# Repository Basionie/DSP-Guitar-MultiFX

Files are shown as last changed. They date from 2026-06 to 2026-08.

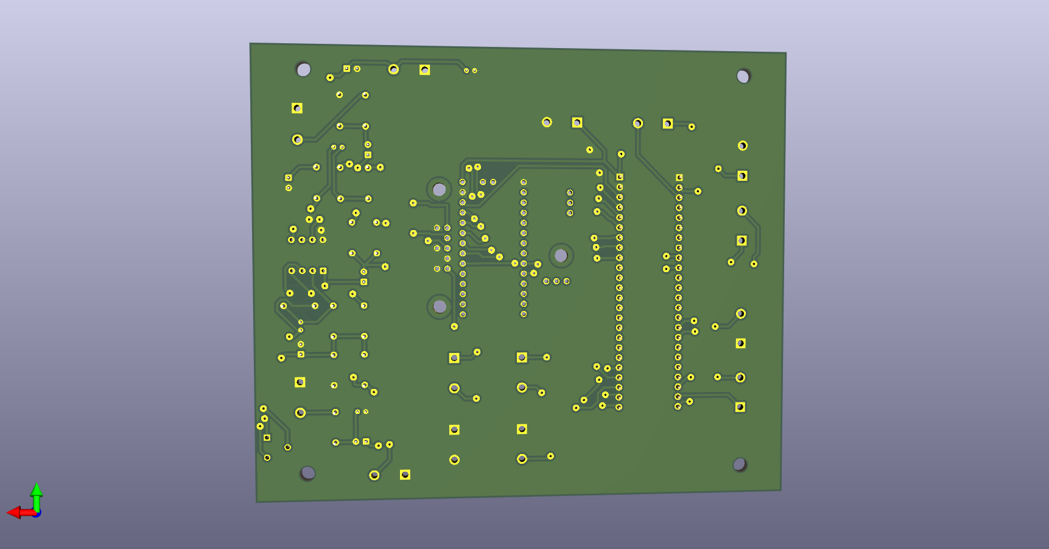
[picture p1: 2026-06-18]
Images/pcb_bottom_3d.png

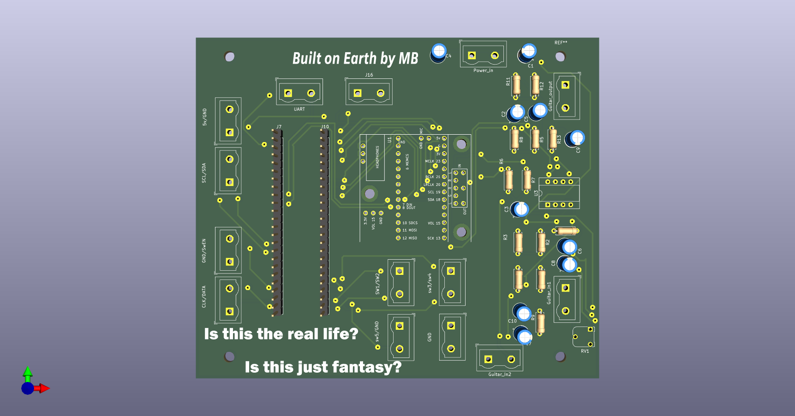
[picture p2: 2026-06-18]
Images/pcb_top_3d.png

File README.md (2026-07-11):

# DSP-Guitar-MultiFX

A modular, high-performance guitar multi-effects processor built on the Teensy 4.1. This project features a professional-grade audio graph, real-time parameter control, and a scalable architecture for adding new audio effects.

🛠️ Features
Modular Architecture: Isolated namespaces for DSP, audio routing, and UI logic.

Audio Effects: Currently supports Chorus, Delay, and Reverb.

Hardware Interface: Integrated support for SGTL5000 audio shield, rotary encoder for navigation, and display integration.

Scalable Design: Easily add new effects by implementing the IEffect interface.

🚀 Getting Started
Clone the repository: git clone [https://github.com/Basionie/DSP-Guitar-MultiFX.git](https://github.com/Basionie/DSP-Guitar-MultiFX.git)

Setup: Open the firmware/ folder in VS Code with the PlatformIO extension.

Build: Use the PlatformIO "Build" button to compile the firmware.

Upload: Connect your Teensy 4.1 via USB and click "Upload".

⚙️ How to Add New Effects
To add a new effect (e.g., Distortion):

Create effects/distortion.h and distortion.cpp.

Implement the IEffect interface.

Register the new effect in the EffectManager to enable UI control.

📜 Dependencies
U8g2 (Display driver)

CriticalTaskScheduler 
(Task scheduling)

7448d674-3cfc-4cf9-ab88-5cb7c3a28c2d

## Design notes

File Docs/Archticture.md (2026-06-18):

# DSP Guitar Effects Pedal Architecture (Teensy 4.1)

## System Overview

The system is a real-time digital audio processing pedal built on the Teensy 4.1 microcontroller.

A guitar input signal is captured, processed through a modular DSP effects chain, and output with minimal latency suitable for live performance.

---

## Signal Flow

Guitar Input  
→ Analog Front-End (signal conditioning)  
→ Audio Codec (ADC via SGTL5000)  
→ Teensy 4.1 DSP Processing Core  
→ Effects Processing Chain  
→ Audio Codec (DAC)  
→ Output to amplifier / speaker

---

## DSP Processing Pipeline

Audio is processed in real time using a block-based streaming architecture:

1. Audio buffer acquisition (input block)
2. Pre-processing (gain control / normalization)
3. Effects chain processing:
   - Distortion (non-linear waveshaping)
   - Delay (buffer-based echo)
   - Reverb (Algorithmic Reverb)
4. Mixing and output gain control
5. Output buffer transmission

---

## Hardware Architecture

- Teensy 4.1 (ARM Cortex-M7 @ 600 MHz)
- Audio Shield (SGTL5000 codec)
- Guitar input jack with analog conditioning circuit
- Audio output to amplifier or speaker system

---

## Software Architecture

The firmware is modular and built around the Teensy Audio Library.

Main components:

- `audio_input.cpp` → Handles audio input stream
- `audio_engine.cpp` → Manages DSP pipeline and routing
- `effects/` → Individual effect modules (distortion, delay, reverb)
- `config.h` → Global parameters (gain, mix, effect levels)

The system uses interrupt-driven, real-time audio processing with fixed-size audio blocks.

---

## Real-Time Constraints

- Target latency: < 10 ms
- Block-based processing using Teensy Audio Library
- Optimized for ARM Cortex-M7 DSP instructions
- No dynamic memory allocation in the audio processing path
- Deterministic execution per audio block

---

## Expandability

The architecture is designed to support future enhancements:

- Footswitch / pedal control input
- Preset saving and loading system
- External UI (OLED display)

---

## Summary

This architecture provides a scalable and real-time DSP framework for guitar audio processing on embedded hardware, balancing performance, modularity, and low latency.

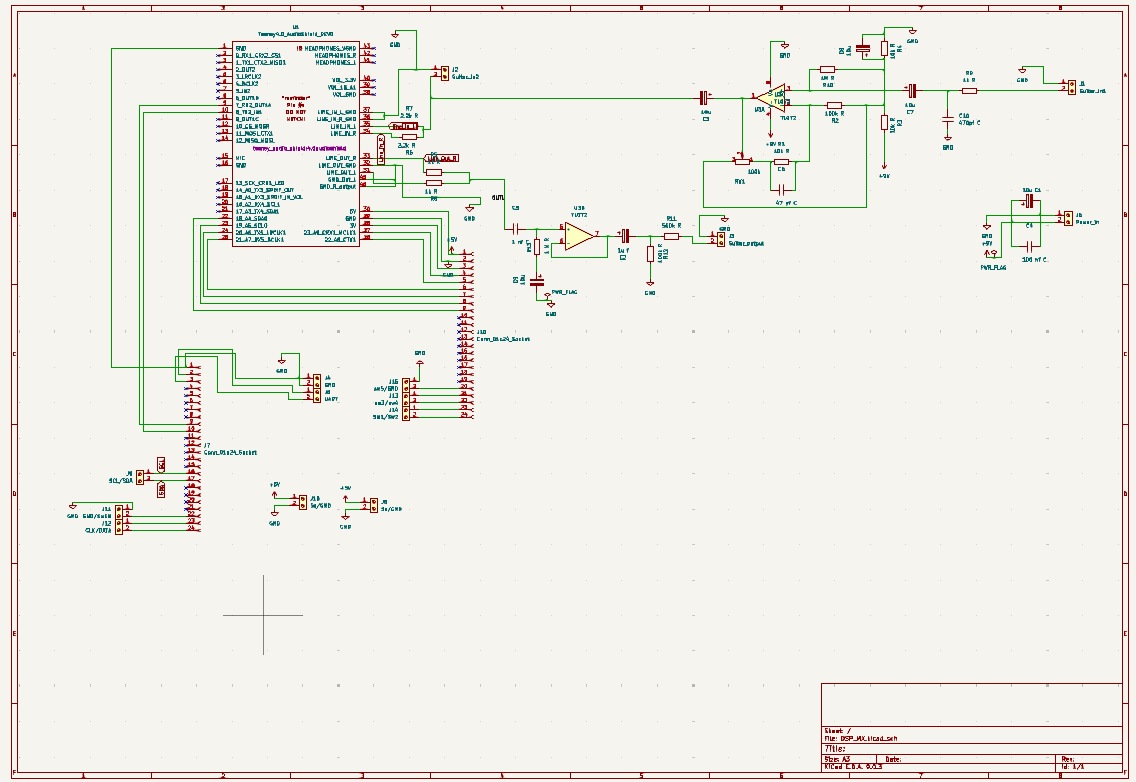
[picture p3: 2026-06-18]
Images/schematic.png

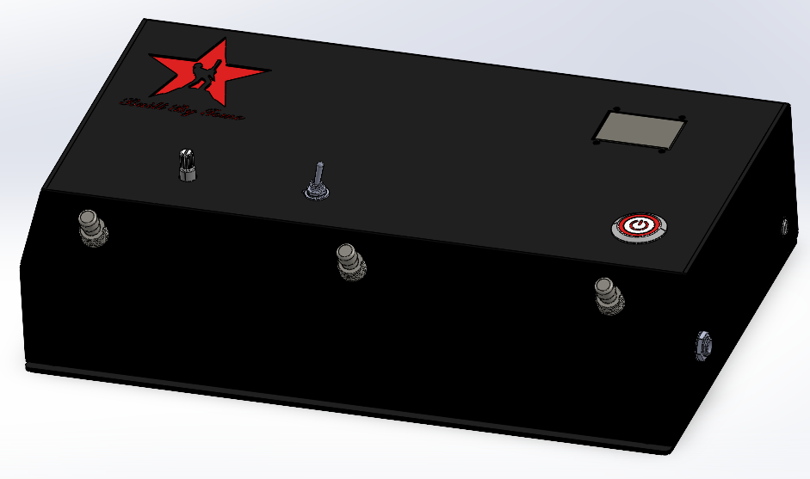
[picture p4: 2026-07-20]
Images/DSP_Final_Desing.png

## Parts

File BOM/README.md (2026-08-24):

# Bill of Materials (BOM)

> **Note:** The components listed in this BOM were primarily sourced from local suppliers in Egypt in prototyping/non-production quantities. Prices are provided for reference only.

Please refer to [`Project_BOM.xlsx`](./Project_BOM.xlsx) for the full itemized components list and cost analysis.

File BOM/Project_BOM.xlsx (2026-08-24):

HARDWARE PROJECT BILL OF MATERIALS (BOM)
The components listed in this BOM were primarily purchased from suppliers in Egypt and in non-production quantities. Prices are provided for reference only and may vary depending on the supplier, country, exchange rates, availability, and purchase quantity. Bulk or mass-production purchases may have significantly different pricing.
Item | Component | Value / Specification | Manufacturer | Part Number | Quantity | Unit Price (EGP) | Total (EGP) | Unit Price (USD) | Total (USD) | Source | Link
1 | Microcontroller | Teensy 4.1 Board | PJRC | DEV-16771 | 1 | 1575.00 | 1575.00 | $31.50 | $31.50 | SparkFun | https://www.sparkfun.com/teensy-4-1.html
2 | Audio Codec | Teensy 4 Audio Shield (Rev D) | PJRC | DEV-15845 | 1 | 490.00 | 490.00 | $9.80 | $9.80 | SparkFun | https://www.sparkfun.com/teensy-4-audio-shield-rev-d.html
3 | Op-Amp | Low Noise JFET Dual Operational Amplifier | Generic / ST | TL072CN | 2 | 17.00 | 34.00 | $0.34 | $0.68 | RAM Electronics | https://www.ram-e-shop.com/ar/shop/tl072-tl072cn-5722
4 | Capacitor | 10 µF | Generic | C.10U450V | 1 | 3.50 | 3.50 | $0.07 | $0.07 | RAM Electronics | https://www.ram-e-shop.com/ar/shop/c-10u450v-capacitor-mkthf-kymyyy-10uf-mykrw-frd-450v-fwlt-6105
5 | Capacitor | 1 µF | Generic | C.1U50V | 1 | 0.65 | 0.65 | $0.01 | $0.01 | RAM Electronics | https://www.ram-e-shop.com/ar/shop/c-1u50v-capacitor-mkthf-kymyyy-1uf-mykrw-frd-50v-fwlt-6075
6 | Capacitor | 100 nF Ceramic | Generic | C.PF.104 | 2 | 0.75 | 1.50 | $0.01 | $0.03 | RAM Electronics | https://www.ram-e-shop.com/ar/shop/c-pf-104-capacitor-mkthf-pf104-syrmyk-100-nnw-frd-25-fwlt-100nf-25v-6240
7 | Capacitor | 1 nF Ceramic | Generic | C.PF.102 | 1 | 0.50 | 0.50 | $0.01 | $0.01 | RAM Electronics | https://www.ram-e-shop.com/ar/shop/c-pf-102-capacitor-mkthf-pf102-syrmyk-1-nnw-frd-25-fwlt-1nf-25v-6239
8 | Capacitor | 4.7 µF | Generic | C.4.7U50V | 2 | 0.75 | 1.50 | $0.01 | $0.03 | Lampatronics | https://www.ram-e-shop.com/ar/shop/c-4-7u50v-capacitor-mkthf-kymyyy-4-7uf-mykrw-frd-50v-fwlt-6066
9 | Capacitor | 100 µF | Generic | C.100U50V | 1 | 1.50 | 1.50 | $0.03 | $0.03 | Lampatronics | https://www.ram-e-shop.com/ar/shop/c-100u50v-capacitor-mkthf-kymyyy-100uf-mykrw-frd-50v-fwlt-6073
10 | Resistor | 10 kΩ 1/4W Carbon Film | Generic | R.10k.1/4W | 2 | 0.25 | 0.50 | $0.01 | $0.01 | RAM Electronics | https://www.ram-e-shop.com/ar/shop/carbon-resistance-1-4w-price-per-4-resistors-9506#attr=314
11 | Resistor | 100 kΩ 1/4W Carbon Film | Generic | R.100K.1/4W | 2 | 0.25 | 0.50 | $0.01 | $0.01 | RAM Electronics | https://www.ram-e-shop.com/ar/shop/carbon-resistance-1-4w-price-per-4-resistors-9506#attr=317
12 | Resistor | 1 kΩ 1/4W Carbon Film | Generic | R.1K.1/4W | 2 | 0.25 | 0.50 | $0.01 | $0.01 | RAM Electronics | https://www.ram-e-shop.com/ar/shop/carbon-resistance-1-4w-price-per-4-resistors-9506#attr=309
13 | Resistor | 2.2k Ω 1/4W Carbon Film | Generic | R.2.2K.1/4W | 2 | 0.25 | 0.50 | $0.01 | $0.01 | RAM Electronics | https://www.ram-e-shop.com/ar/shop/carbon-resistance-1-4w-price-per-4-resistors-9506#attr=310
14 | Resistor | 1M Ω 1/4W Carbon Film | Generic | R.1M.1/4W | 2 | 0.25 | 0.50 | $0.01 | $0.01 | RAM Electronics | https://www.ram-e-shop.com/ar/shop/carbon-resistance-1-4w-price-per-4-resistors-9506#attr=321
15 | Resistor | 560k Ω 1/4W Carbon Film | Generic | R.560K.1/4W | 1 | 0.25 | 0.25 | $0.01 | $0.01 | RAM Electronics | https://www.ram-e-shop.com/ar/shop/carbon-resistance-1-4w-price-per-4-resistors-9506#attr=320
16 | Potentiometer | 100 kΩ Carbon Trimmer (Top Adjust) | Generic | POT.100K.SMALL | 1 | 2.50 | 2.50 | $0.05 | $0.05 | RAM Electronics | https://www.ram-e-shop.com/ar/shop/pot-100k-small-top-adjust-potentiometer-100ko-5838
17 | Audio Jack / Connector | 6.35mm (1/4") Female Mono TS Socket Panel Mount | LOCHSOEL | LOCHSOEL-6.35MM-6PACK | 2 | 75.00 | 150.00 | $1.50 | $3.00 | Amazon Egypt | https://www.amazon.com/6-35mm-Female-Microphone-Connector-Adapter/dp/B08MT66VPX
18 | Footswitch | SPST Momentary Push Button Stomp Foot Switch (2 Pin) | Gebildet | Gebildet-Stomp-SPST | 3 | 250.00 | 750.00 | $5.00 | $15.00 | Amazon Egypt | https://www.amazon.com/s
19 | Power Switch | 22mm Metal Push Button, 12-24V Self-Locking with Red LED | Generic | 6124 | 1 | 185.00 | 185.00 | $3.70 | $3.70 | Ampere Electronics | https://ampere-electronics.com/product/metal-push-button-22mm-power-red-light/
20 | Encoder | EC11 Rotary Encoder with Push Switch (5-Pin, 20mm Shaft) | Generic | EC11 | 1 | 25.00 | 25.00 | $0.50 | $0.50 | RAM Electronics | https://www.ram-e-shop.com/ar/shop/pot-ec11-rotary-5pin-20mm-ec11-rotary-encoder-with-push-button-switch-5pin-20mm-silver-9624
21 | Display Module | 1.3" OLED Display, 128x64, Blue, 4-Pin I2C (SH1106 Driver) | Generic | 26346 | 1 | 250.00 | 250.00 | $5.00 | $5.00 | Ampere Electronics | https://ampere-electronics.com/product/1-3-inch-oled-display-module-blue-128x64-4pin-i2c/
22 | Switch | DPDT Toggle Switch 6-Pin 2-Position (ON-ON) 6A 125VAC | Generic | MTS-202 | 1 | 13.00 | 13.00 | $0.26 | $0.26 | RAM Electronics | https://www.ram-e-shop.com/ar/shop/toggle-6pin-toggle-switch-6-pin-2-position-mts-202-5730
23 | Connector | Male Pin Header 1x40 Straight 2.54mm Pitch (Long Leg 17mm) | Generic | PH10-1X40-MALE | 3 | 4.00 | 12.00 | $0.08 | $0.24 | RAM Electronics | https://www.ram-e-shop.com/ar/shop/ph10-1x40-male-ph10-pin-header-male-1x40-straight-2-54mm-long-leg-17mm-5832
24 | Connector | Female Pin Header 1x40 Straight 2.54mm Pitch | Generic | PH2-1X40-FEMALE | 3 | 5.00 | 15.00 | $0.10 | $0.30 | RAM Electronics | https://www.ram-e-shop.com/ar/shop/ph2-1x40-female-ph2-pin-header-female-1x40-straight-2-54mm-5833
25 | Connector | 2-Pin Barrier Terminal Block 7.62mm Pitch (PCB Mount) | Generic | RP2.POWER.ROS2PIN | 14 | 3.50 | 49.00 | $0.07 | $0.98 | RAM Electronics | https://www.ram-e-shop.com/ar/shop/rp-2-power-ros2pin-rp2-2-pin-barrier-terminal-block-pitch-7-62mm-5805
26 | Jumper Wires | Male to Female Jumper Wire 30cm (1-Pin) | Generic | PH.MALE.FEMALE.30CM | 50 | 1.50 | 75.00 | $0.03 | $1.50 | RAM Electronics | https://www.ram-e-shop.com/ar/shop/ph-male-female-30cm-phcr-m-f-30cm-male-to-female-1-jumper-wire-6808
27 | Connector | Insulated 6.3mm Female Spade Crimp Terminal (AWG 12-10) | Generic | FDD5.5-250 | 15 | 2.00 | 30.00 | $0.04 | $0.60 | RAM Electronics | https://www.ram-e-shop.com/ar/shop/fdd5-5-250-insulated-6-3mm-female-blade-electrical-crimp-terminal-connector-5733
28 | Hardware | M3x12mm Phillips Pan Head Screw | Generic | 26570 | 1 | 4.00 | 4.00 | $0.08 | $0.08 | Ampere Electronics | https://ampere-electronics.com/product/m3x12-phillips-pan-head-screw/
29 | Hardware | M3 Galvanized Steel Hex Nut | Generic | 24566 | 1 | 9.00 | 9.00 | $0.18 | $0.18 | Ampere Electronics | https://ampere-electronics.com/product/m3-galvanized-steel-hex-nut-pack-of-10/
30 | Wire / Cable | 2-Core Speaker Wire 1mm Red & Black (1 Meter) | Generic | WIRE-2CORE-1MM | 4 | 9.5 | 38.00 | $0.19 | $0.76 | RAM Electronics | https://www.ram-e-shop.com/ar/shop/wire-speaker-2x1mm-speaker-wire-2-core-x-1mm-red-black-1-meter-slk-khrby-sm-t-lltwsyl-2-trf-hmr-w-swd-qtr-1-mly-1-mtr-8878
31 | Insulation | Heat Shrink Tubing Kit (164 pcs Assorted Colors) | Generic | H.SH.SET.164.COLOR | 1 | 50.00 | 50.00 | $1.00 | $1.00 | RAM Electronics | https://www.ram-e-shop.com/ar/shop/h-sh-set-164-color-bag-of-heat-shrink-164pcs-set-color-kys-shrnk-mkrwn-hrry-ll-zl-mlwn-164-qt-9303
32 | Consumables | Solder Wire 100g Sn70/Pb30 0.6mm (2% Flux Core) | Generic | SOLDER.WIRE.RAM.100GM | 1 | 395.00 | 395.00 | $7.90 | $7.90 | RAM Electronics | https://www.ram-e-shop.com/ar/shop/solder-wire-ram-100gm-solder-wire-ram-high-quality-100gm-sn70-pb30-qsdyr-lhm-ly-ljwd-mrk-rm-bkr-100jm-nsb-lqsdyr-l-lrss-70-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
33 | Connector | DC Female Power Plug 2.1mm to 2-Pin Screw Terminal | Generic | R.3.TO.DC.FEMALE | 1 | 40.00 | 40.00 | $0.80 | $0.80 | RAM Electronics | https://www.ram-e-shop.com/ar/shop/r-3-to-dc-female-dc-female-power-plug-2-1mm-to-2pin-screw-terminal-block-7113
34 | Power Supply | 9V Alkaline Battery (6LR61) | Toshiba | BATTERY9V.PLUS.ALKALINE | 1 | 175.00 | 175.00 | $3.50 | $3.50 | RAM Electronics | https://www.ram-e-shop.com/ar/shop/battery9v-plus-alkaline-battery-9v-power-alkaline-philips-btry-9-fwlt-fylybs-lklyn-mr-twl-7690
35 | Hardware | 2xAA Battery Holder with Cover & On/Off Switch | Generic | BATTERY.CASE.2XAA.ONOFF | 1 | 18.00 | 18.00 | $0.36 | $0.36 | RAM Electronics | https://www.ram-e-shop.com/ar/shop/battery-case-2xaa-onoff-battery-holder-2xaa-on-off-switch-jrb-hml-btry-m-mfth-6137
36 | PCB | Custom 2-Layer Printed Circuit Board (FR-4) | External PCB Manufacturer | PCB-PROJ-V1 | 1 | 700.00 | 700.00 | $14.00 | $14.00 | Avengers Robotics | https://www.facebook.com/avengersrobotics1
37 | Enclosure | Custom Sheet Metal Enclosure / Chassis | Custom / In-House | CHASSIS-SM-01 | 1 | 600.00 | 600.00 | $12.00 | $12.00 | Custom Fabricated
Hardware subtotal: |  |  |  |  |  |  | 5696.40 |  | $113.93

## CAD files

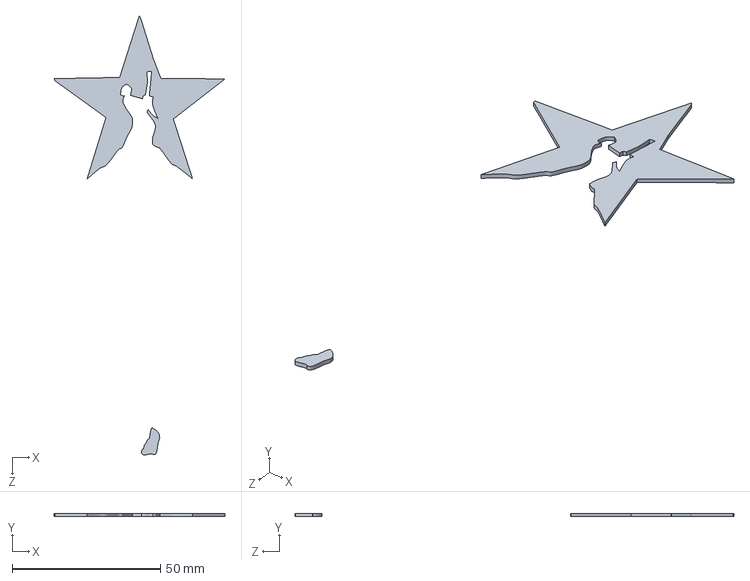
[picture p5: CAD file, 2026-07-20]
Mechanical/DSP_3D_Design/Part5.SLDPRT
57.6 x 1.00 x 147.9 mm

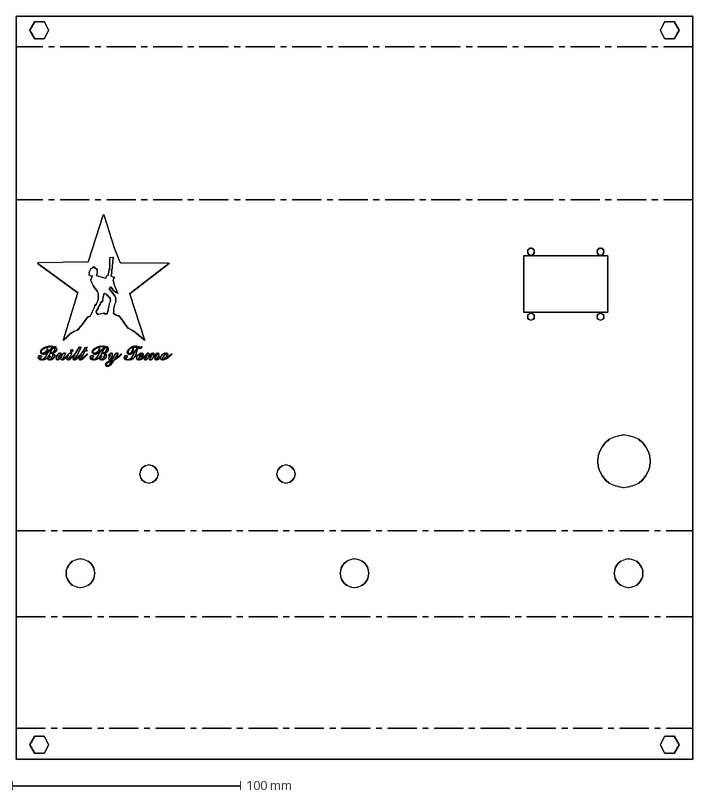
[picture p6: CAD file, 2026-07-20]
Mechanical/DSP_dxf/Flat pattern - Part1.DXF
296.0 x 325.3 mm

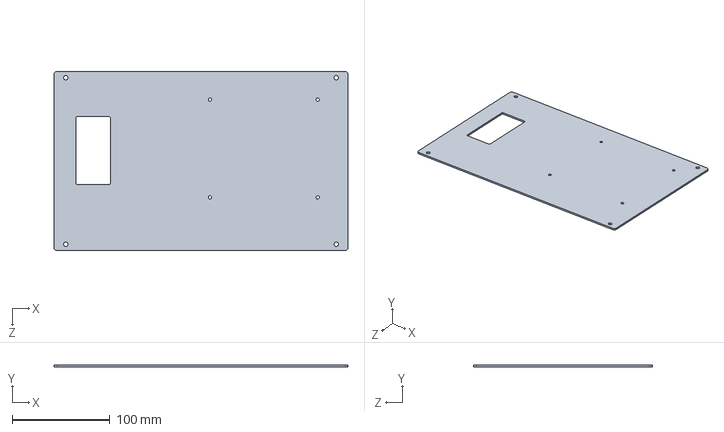
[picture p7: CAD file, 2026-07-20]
Mechanical/DSP_3D_Design/Part3.SLDPRT
300.0 x 2.00 x 183.0 mm

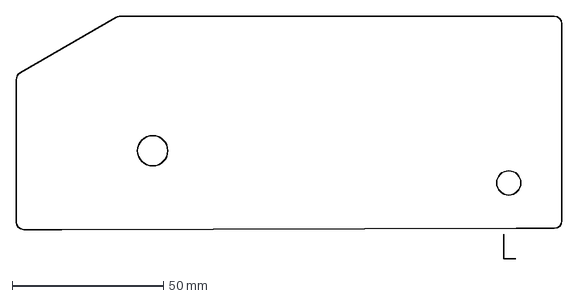
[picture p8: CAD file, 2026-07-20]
Mechanical/DSP_dxf/Flat pattern - Part2.DXF
180.2 x 80.0 mm

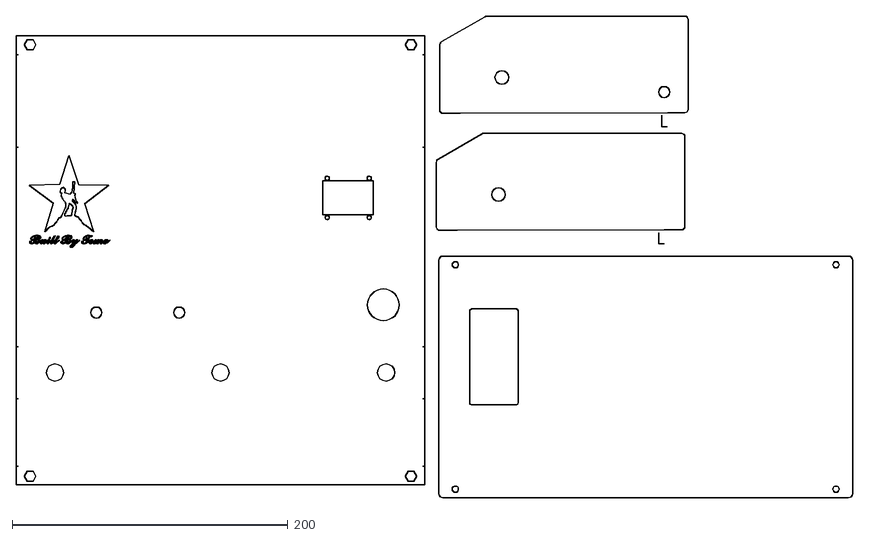
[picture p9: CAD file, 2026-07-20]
Mechanical/DSP_dxf/All_Parts.dxf
606.2 x 349.1

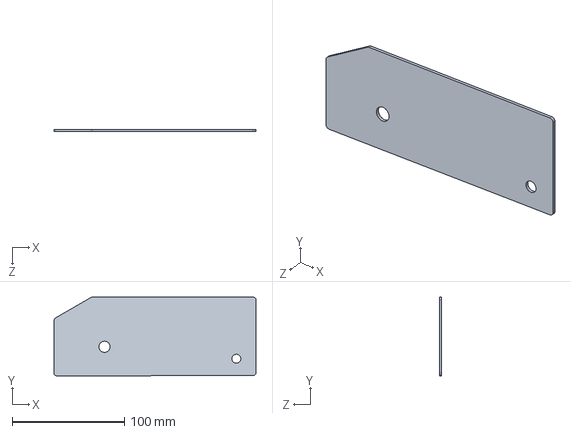
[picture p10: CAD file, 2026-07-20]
Mechanical/DSP_3D_Design/Part2.SLDPRT
180.2 x 70.4 x 2.00 mm

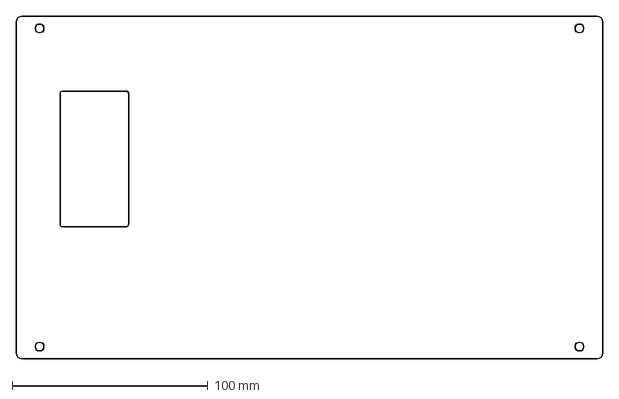
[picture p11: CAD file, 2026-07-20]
Mechanical/DSP_dxf/Flat pattern - Part3.DXF
300.0 x 175.2 mm

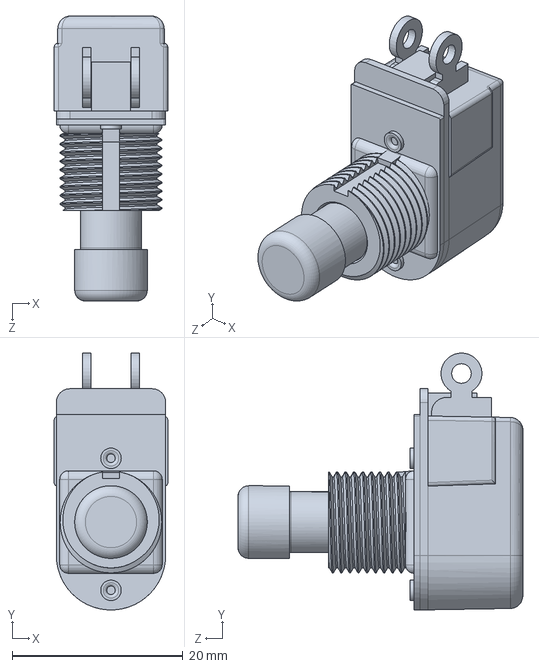
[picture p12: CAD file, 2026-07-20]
Mechanical/DSP_3D_Design/Momentary footswitch.SLDPRT
13.3 x 30.1 x 33.3 mm

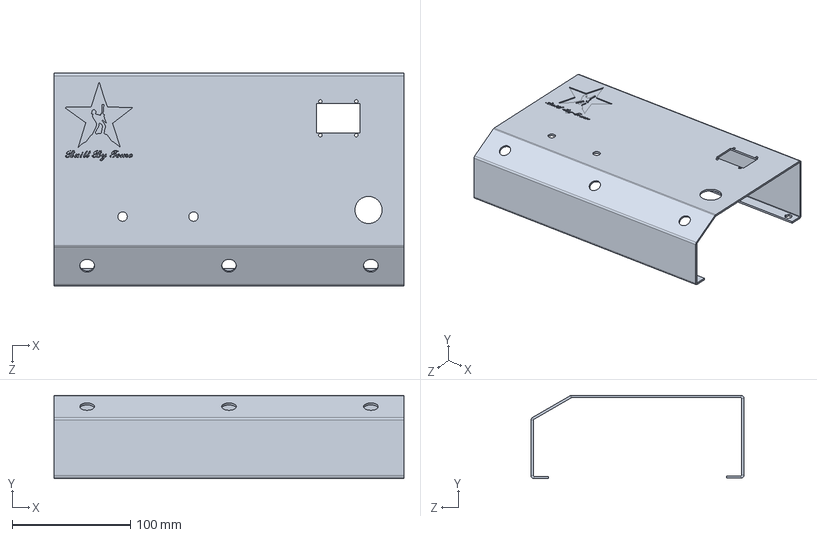
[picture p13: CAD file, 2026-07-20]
Mechanical/DSP_3D_Design/Part1.SLDPRT
296.0 x 70.4 x 180.2 mm

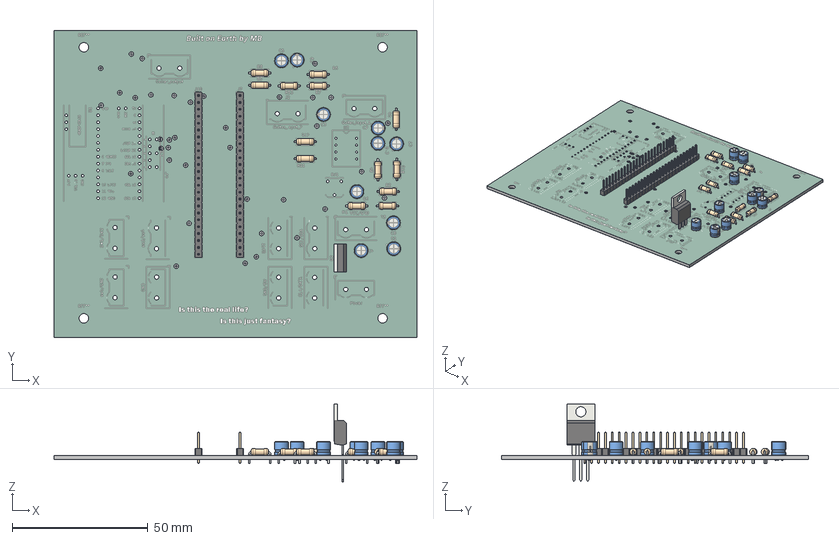
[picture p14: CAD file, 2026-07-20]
Mechanical/DSP_3D_Design/DSP_MX.step
133.6 x 112.9 x 28.5 mm
CP_Radial_D5.0mm_P2.50mm x 6
C_Radial_D5.0mm_H5.0mm_P2.00mm x 4
R_Axial_DIN0207_L6.3mm_D2.5mm_P7.62mm_Horizontal x 13
PinHeader_1x24_P2.54mm_Vertical x 2
TO-220-3_Vertical
DSP_MX_silkscreen
DSP_MX_soldermask
DSP_MX_PCB

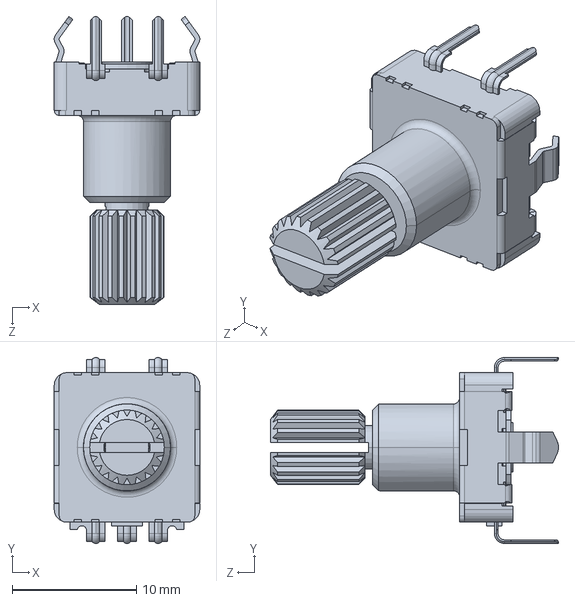
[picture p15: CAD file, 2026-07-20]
Mechanical/DSP_3D_Design/EC11 Rotary Encoder Dode Switch-15mm.SLDPRT
11.7 x 14.9 x 23.2 mm

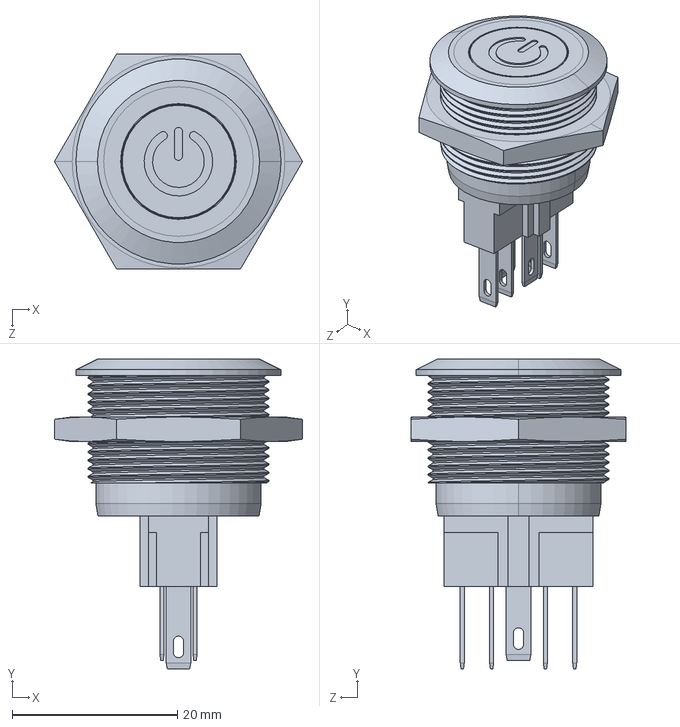
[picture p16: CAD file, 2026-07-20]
Mechanical/DSP_3D_Design/Metal Push button Switch with ring LED 22mm.SLDPRT
30.0 x 37.5 x 26.0 mm

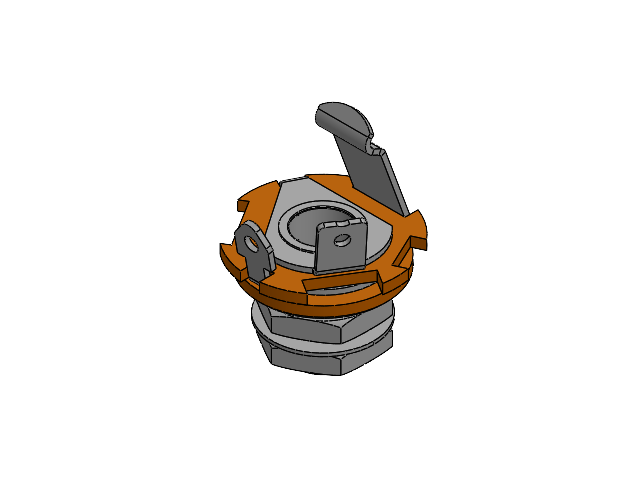
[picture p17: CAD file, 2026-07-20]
Mechanical/DSP_3D_Design/Squaer_socket.SLDASM
Washer005.step
Sleeve001.step
Common_contact001.step
Washer003.step
Output_contact001.step
Washer004.step
Wacher005.step
Thread001.step
Body009.step
Body023.step
Washer006.step

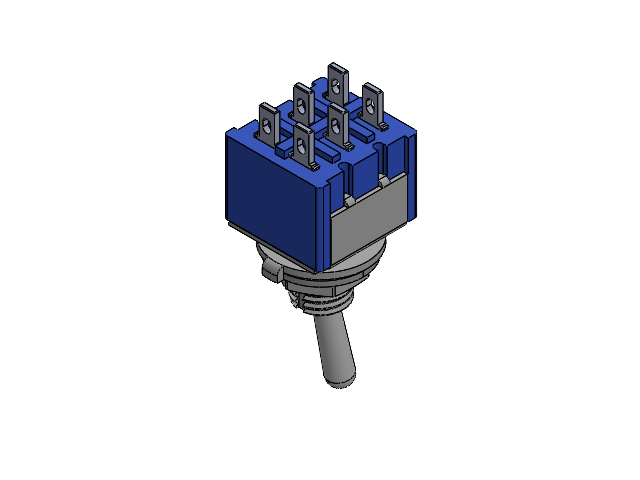
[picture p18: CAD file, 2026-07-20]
Mechanical/DSP_3D_Design/MTS-202.SLDASM
Terminal_1.step x 6
Metal_part_1.step
Polyamid_body.step
Handle.step
Nut_H_1.step
Internal_Tooth_Lock_Washers_1.step
Keyed_wafer.step
Nut_B_1.step

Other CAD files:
Mechanical/DSP_3D_Design/mts102.SLDASM
Mechanical/DSP_3D_Design/Assem1.SLDASM
Mechanical/DSP_3D_Design/Part4.SLDPRT
Mechanical/DSP_3D_Design/DSP_MX.step.SLDPRT
Mechanical/DSP_3D_Design/DSP_Design.STEP
Mechanical/DSP_3D_Design/Female DC-Power-to-Screw-Terminals-Adapter.SLDPRT
Mechanical/DSP_3D_Design/Geekcreit 1.3 Inch 4Pin.step.SLDPRT
Mechanical/DSP_dxf/All_Parts.dwg
Mechanical/DSP_dxf/Flat pattern - Part1.dwg
Mechanical/DSP_dxf/Flat pattern - Part2.dwg
Mechanical/DSP_dxf/Flat pattern - Part3.dwg

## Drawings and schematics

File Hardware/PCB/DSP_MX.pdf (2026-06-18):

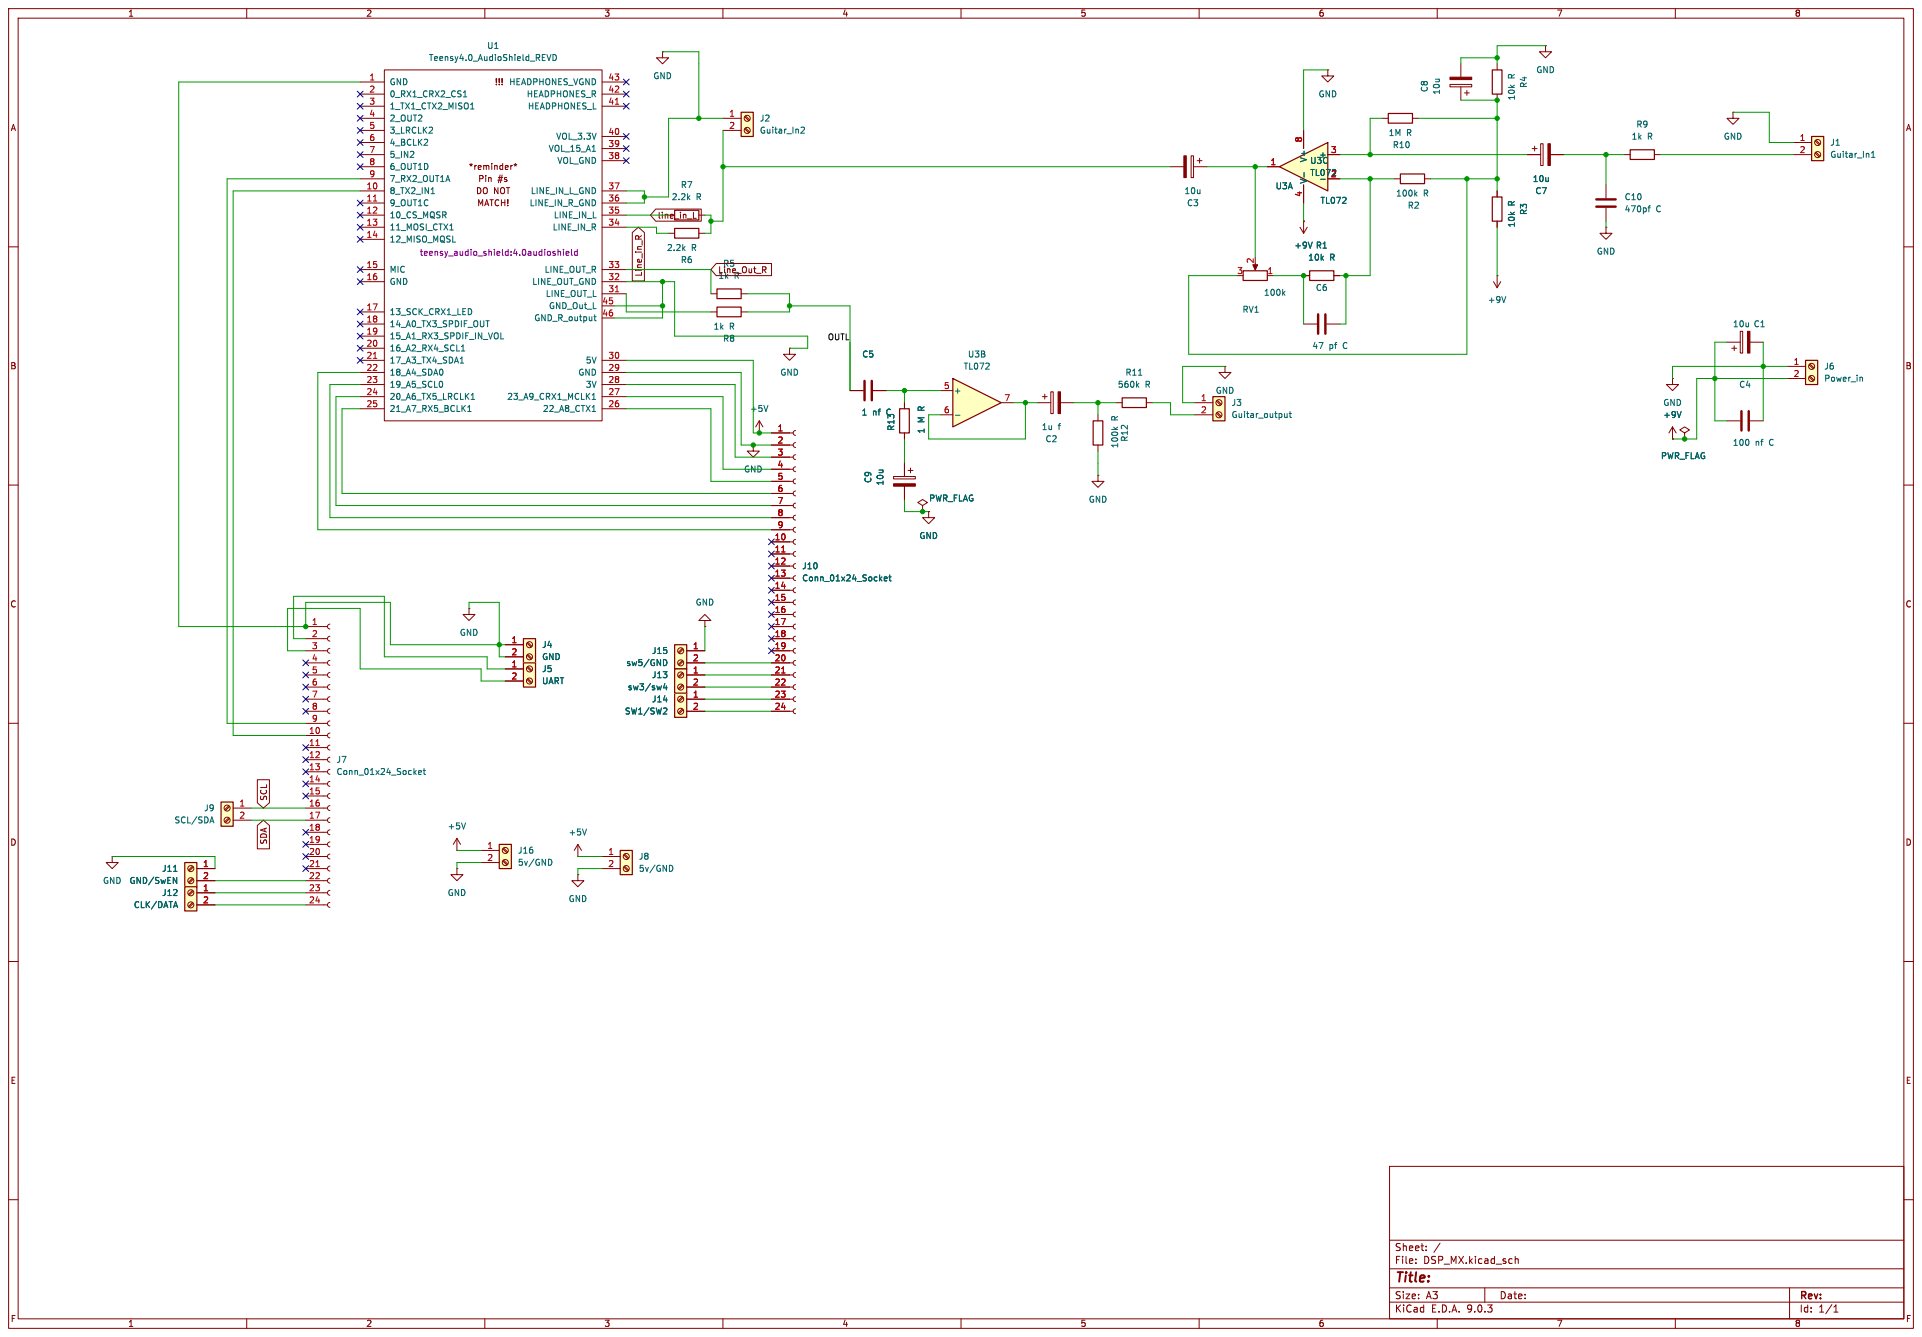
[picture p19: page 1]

*reminder* Pin #s DO NOT MATCH!

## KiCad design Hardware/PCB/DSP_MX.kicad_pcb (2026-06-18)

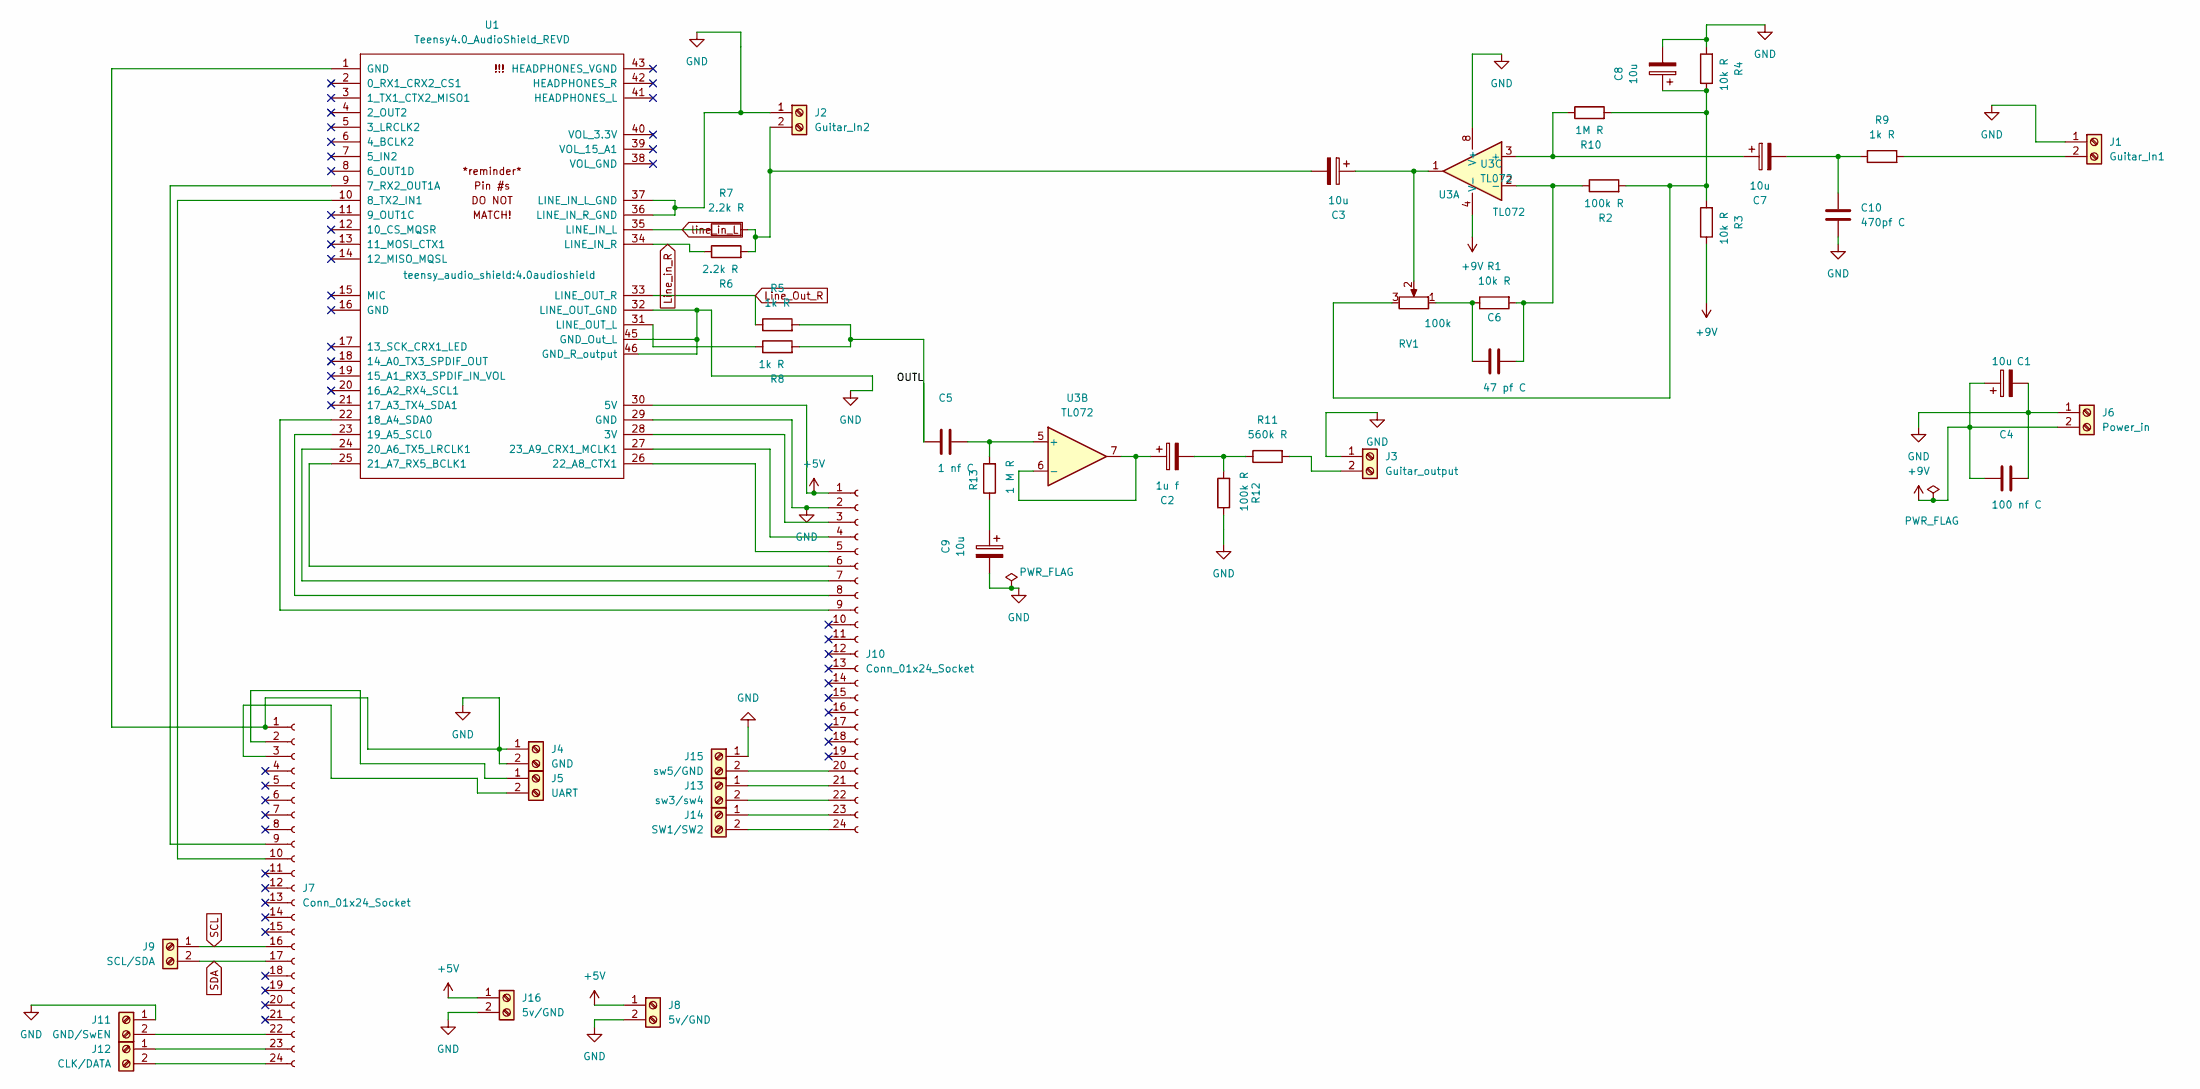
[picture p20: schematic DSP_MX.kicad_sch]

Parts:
C1, C3, C7, C8, C9: 10u; CP_Radial_D5.0mm_P2.50mm
C2: 1u f; CP_Radial_D5.0mm_P2.50mm
C4: 100 nf C; C_Radial_D5.0mm_H5.0mm_P2.00mm
C5: 1 nf C; C_Radial_D5.0mm_H5.0mm_P2.00mm
C6: 47 pf C; C_Radial_D5.0mm_H5.0mm_P2.00mm
C10: 470pf C; C_Radial_D5.0mm_H5.0mm_P2.00mm
J1: Guitar_In1; TerminalBlock_Wuerth_691311400102_P7.62mm
J2: Guitar_In2; TerminalBlock_Wuerth_691311400102_P7.62mm
J3: Guitar_output; TerminalBlock_Wuerth_691311400102_P7.62mm
J4: GND; TerminalBlock_Wuerth_691311400102_P7.62mm
J5: UART; TerminalBlock_Wuerth_691311400102_P7.62mm
J6: Power_in; TerminalBlock_Wuerth_691311400102_P7.62mm
J7, J10: Conn_01x24_Socket; PinHeader_1x24_P2.54mm_Vertical
J8, J16: 5v/GND; TerminalBlock_Wuerth_691311400102_P7.62mm
J9: SCL/SDA; TerminalBlock_Wuerth_691311400102_P7.62mm
J11: GND/SwEN; TerminalBlock_Wuerth_691311400102_P7.62mm
J12: CLK/DATA; TerminalBlock_Wuerth_691311400102_P7.62mm
J13: sw3/sw4; TerminalBlock_Wuerth_691311400102_P7.62mm
J14: SW1/SW2; TerminalBlock_Wuerth_691311400102_P7.62mm
J15: sw5/GND; TerminalBlock_Wuerth_691311400102_P7.62mm
R1, R3, R4: 10k R; R_Axial_DIN0207_L6.3mm_D2.5mm_P7.62mm_Horizontal
R2, R12: 100k R; R_Axial_DIN0207_L6.3mm_D2.5mm_P7.62mm_Horizontal
R5, R8, R9: 1k R; R_Axial_DIN0207_L6.3mm_D2.5mm_P7.62mm_Horizontal
R6, R7: 2.2k R; R_Axial_DIN0207_L6.3mm_D2.5mm_P7.62mm_Horizontal
R10: 1M R; R_Axial_DIN0207_L6.3mm_D2.5mm_P7.62mm_Horizontal
R11: 560k R; R_Axial_DIN0207_L6.3mm_D2.5mm_P7.62mm_Horizontal
R13: 1 M R; R_Axial_DIN0207_L6.3mm_D2.5mm_P7.62mm_Horizontal
RV1: 100k; Potentiometer_Runtron_RM-065_Vertical
U1: Teensy4.0_AudioShield_REVD; 4.0audioshield
U3: TL072; CERDIP-8_W7.62mm_SideBrazed_Socket

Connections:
+5V: J8.1, J10.1, J16.1, U1.30 (5V)
+9V: C1.1, C4.2, J6.2, R3.1, U3.4 (V-)
/OUTL: C5.2, R5.2, R8.2
GND: C1.2, C4.1, C8.2, C9.2, C10.2, J1.1, J2.1, J3.1, J4.1, J4.2, J6.1, J7.1, J8.2, J10.2, J11.1, J15.1, J16.2, R4.2, R12.1, U1.1 (GND), U1.29 (GND), U1.32 (LINE_OUT_GND), U1.36 (LINE_IN_R_GND), U1.37 (LINE_IN_L_GND), U1.45 (GND_Out_L), U1.46 (GND_R_output), U3.8 (V+)
Line_Out_R: R5.1, U1.33 (LINE_OUT_R)
Line_in_R: R6.1, U1.34 (LINE_IN_R)
unnamed: C2.2, R11.1, R12.2
unnamed: C3.1, RV1.2, U3.1
unnamed: C6.2, R1.1, RV1.1
unnamed: C8.1, R2.2, R3.2, R4.1, R10.2, RV1.3
unnamed: C9.1, R13.1
unnamed: C7.2, C10.1, R9.1
unnamed: J1.2, R9.2
unnamed: C3.2, J2.2, R6.2, R7.2
unnamed: J3.2, R11.2
unnamed: J5.1, J7.2
unnamed: J5.2, J7.3
unnamed: J7.9, U1.9 (7_RX2_OUT1A)
unnamed: J7.10, U1.10 (8_TX2_IN1)
unnamed: J10.3, U1.28 (3V)
unnamed: J10.4, U1.27 (23_A9_CRX1_MCLK1)
unnamed: J10.5, U1.26 (22_A8_CTX1)
unnamed: J10.6, U1.25 (21_A7_RX5_BCLK1)
unnamed: J10.7, U1.24 (20_A6_TX5_LRCLK1)
unnamed: J10.8, U1.23 (19_A5_SCL0)
unnamed: J10.9, U1.22 (18_A4_SDA0)
unnamed: J10.20, J15.2
unnamed: J10.21, J13.1
unnamed: J10.22, J13.2
unnamed: J10.23, J14.1
unnamed: J10.24, J14.2
unnamed: J7.22, J11.2
unnamed: J7.23, J12.1
unnamed: J7.24, J12.2
unnamed: R8.1, U1.31 (LINE_OUT_L)
unnamed: C7.1, R10.1, U3.3 (+)
unnamed: C6.1, R1.2, R2.1, U3.2 (-)
unnamed: C5.1, R13.2, U3.5 (+)
unnamed: C2.1, U3.6 (-), U3.7
SCL: J7.16, J9.1
SDA: J7.17, J9.2
line_in_L: R7.1, U1.35 (LINE_IN_L)

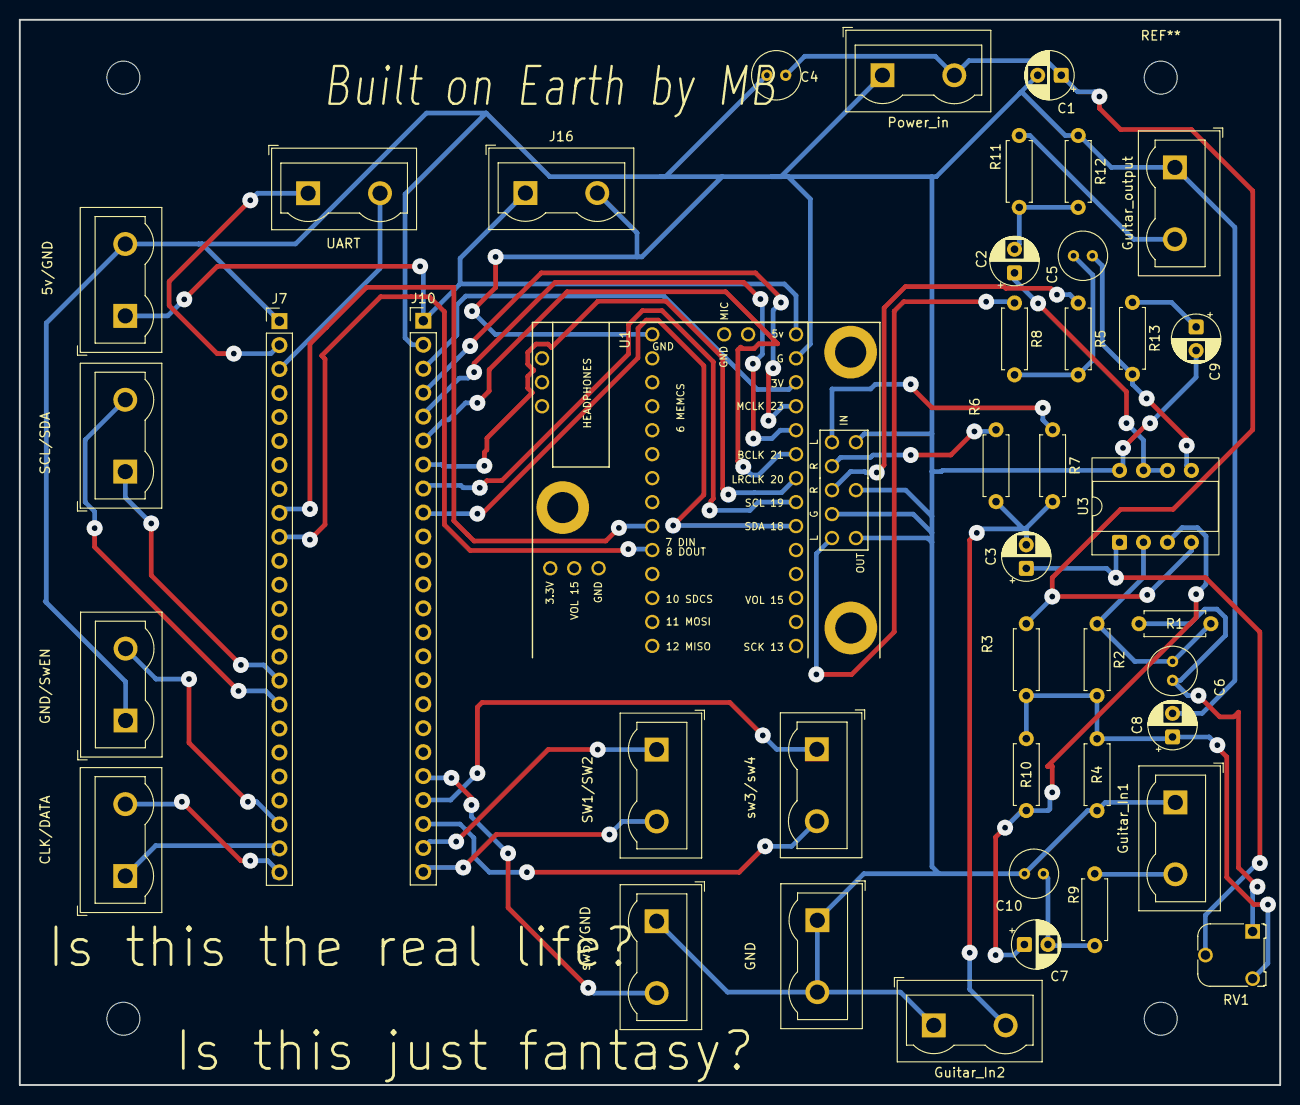
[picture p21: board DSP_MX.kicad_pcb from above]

Board: 2 copper layers, 133.6 x 112.9 mm, 42 parts (0 on the bottom side), 42 nets.

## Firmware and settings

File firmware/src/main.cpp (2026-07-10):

#include <Arduino.h>
#include "core/hardware.h"
#include "core/system.h"
#include "core/scheduler.h"
#include "audio/audio_manager.h"
#include "effects/effect_manager.h"
#include "ui/display.h"
#include "config/constants.h"

void setup() {
    // 1. Start Serial for debugging
    Serial.begin(115200);

    // 2. Initialize low-level hardware (Pins, Encoder, Display)
    initHardware();
    
    // 3. Initialize system interrupts (Footswitches)
    initSystem();

    // 4. Initialize Audio Graph (Memory, I2S, Static Patch Cords)
    AudioManager::init();

    // 5. Initialize Effect wrappers and set default states
    EffectManager::init();

    // 6. Set initial volume and draw the UI
    AudioManager::setSystemVolume(OUTPUT_VOLUME); 
    drawUI(); 

    // 7. Register and enable background tasks
    initScheduler();
}

void loop() {
    // The CriticalTaskScheduler handles all execution.
    // Periodic tasks (Poll, Modulation, UI) run in the background.
    sched.execute(); 
}

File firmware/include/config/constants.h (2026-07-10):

#ifndef CORE_CONSTANTS_H
#define CORE_CONSTANTS_H

// DSP Routing & Gain Constants
constexpr float CHORUS_DRY_GAIN         = 0.6f;
constexpr float REVERB_FROM_DELAY_GAIN  = 0.6f;
constexpr float REVERB_FROM_CHORUS_GAIN = 0.5f;
constexpr float FINAL_DRY_GAIN          = 0.65f;
constexpr float FINAL_WET_GAIN          = 0.75f;

// Filter Constants
constexpr float PRE_FILTER_HZ           = 3200.0f;
constexpr float REPEAT_FILTER_HZ        = 1800.0f;

// Hardware Audio Constants
constexpr float OUTPUT_VOLUME           = 0.7f;
constexpr int   LINEIN_LEVEL            = 9;

// Delay Modulation Base Constants
constexpr float DELAY_MOD_DEPTH_MS      = 3.0f;
constexpr float DELAY_MOD_RATE_HZ       = 0.18f;

// UI & Hardware Timing Constants
constexpr unsigned long DEBOUNCE_DELAY_MS   = 250;
constexpr unsigned long DOUBLE_CLICK_GAP_MS = 400;

#endif // CORE_CONSTANTS_H

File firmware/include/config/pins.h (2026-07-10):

#ifndef CORE_PINS_H
#define CORE_PINS_H

// Display Pins (I2C)
constexpr int PIN_I2C_SDA = 25;
constexpr int PIN_I2C_SCL = 24;

// Rotary Encoder Pins
constexpr int PIN_ENC_A   = 31;
constexpr int PIN_ENC_B   = 32;
constexpr int PIN_BTN_ENC = 30;

// Footswitch Pins
constexpr int PIN_FS_DELAY  = 34;
constexpr int PIN_FS_REVERB = 33;
constexpr int PIN_FS_CHORUS = 35;

// System Master Pins
constexpr int PIN_SYS_BTN = 36;
constexpr int PIN_SYS_LED = 37;

#endif // CORE_PINS_H
